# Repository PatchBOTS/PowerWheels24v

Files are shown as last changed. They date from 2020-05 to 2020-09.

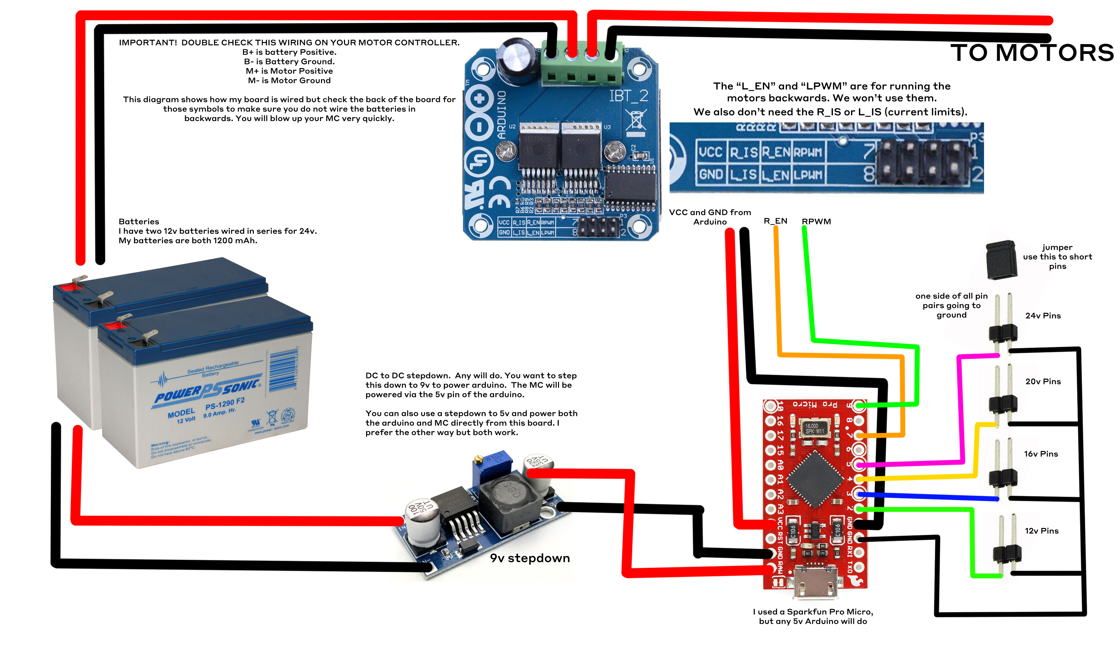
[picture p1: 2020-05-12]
Part1-HappyWife/Jeep Wiring Diagram.jpg

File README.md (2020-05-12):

24V (https://youtu.be/0GJBYLPPLp8)
# PowerWheels Jeep and Lightning McQueen Upgrades
Repository for all code and wiring for the project found in the video above. 
### Please Read Before Proceeding

I am not a professional anything.  This is a modfication I made to my childs vehicle based on my knowledge as a hobbyist and nothing more.  You are wiring batteries together to create more power than the intended use of the vehicle and then putting children in it. Use all the necessary pre-caution, caution and post caution that it deserves.  I take absolutely zero responsibility for anyone elses projects, this is just sharing what I did. I give no gaurantees on anything.  Take that for what it is worth.  

<a href="https://www.buymeacoffee.com/WjRBDa3dZ" target="_blank">Buy Me A Coffee</a>

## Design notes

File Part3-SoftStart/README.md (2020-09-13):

I've added two versions of the code.  The "DCDC" version is if you decide to use the DC to DC stepdown method instead of the digital switch method.

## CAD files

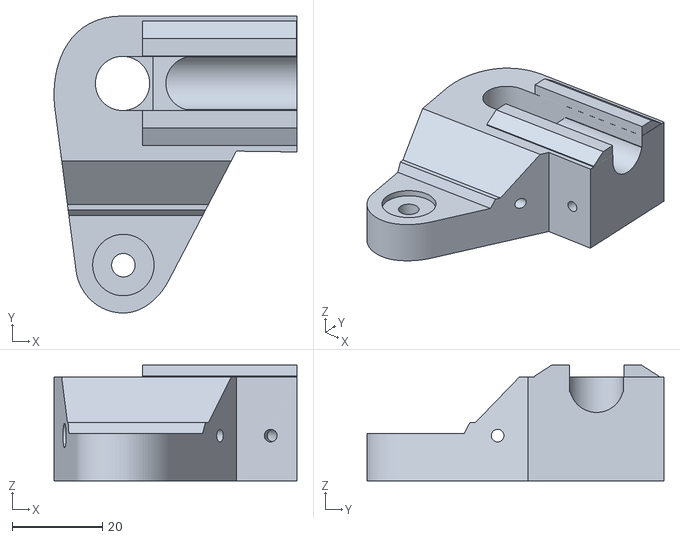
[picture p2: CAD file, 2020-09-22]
Part2-Steering/SteeringKnuckle1.stl
53.8 x 65.8 x 25.7

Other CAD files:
Part2-Steering/SteeringKnuckle2.stl

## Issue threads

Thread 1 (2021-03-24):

knuckle stl file

Mithantrum, 2021-03-24:
Evening! I downloaded the STL file but am not able to get it to open in Prusa Slicer, Blender, Fusion, or Cura. Woulld it be possible to get a re-upload or perhaps the gcode file?
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

DadMode, 2022-09-20:
First time user here. How do I download a file? All I can see is the really long code on the screen when trying to download the STL file. Thanks.

Mithantrum, 2022-09-21:
Just right click, save as. But per my issue above - it doesn't import into the slicer.

> First time user here. How do I download a file? All I can see is the really long code on the screen when trying to download the STL file. Thanks.

WIllyNilly33, 2022-11-18:
I had to drop it into voxelizer to convert to stl (https://drububu.com/miscellaneous/voxelizer/?out=stl). what's lost in translation is the size of the original object, do we know what the mm dimensions are to fit the powerwheel?

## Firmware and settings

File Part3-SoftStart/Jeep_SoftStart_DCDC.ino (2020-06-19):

// =======================================================================================
//                  PowerWheels Conversion-- Jeep Wrangler
// =======================================================================================
//                            Written By: PatchBOTS
// =======================================================================================
//                     microcontroller  ---  Sparkfun Pro Micro (5v)
// --------------------------------------------------------------------------------------
//
//                                 proMicro
//                                ------------
//                                |           |
//                     +--------------------------------+
//                     |                                |
//                     | [ ]TX                   RAW[ ] |  POWER IN
//                     | [ ]RX                   GND[ ] |  GND
//              GND    | [ ]GND                  RST[ ] |
//              GND    | [ ]GND                  VCC[ ] | MotorControllers
//      Speed 1 Jumper | [ ]2                     A3[ ] |
//      Speed 2 Jumper | [ ]3~                    A2[ ] |
//      Speed 3 Jumper | [ ]4                     A1[ ] |
//          Gas Switch | [ ]5~                    A0[ ] |
//           NeoPixel  | [ ]6~                    15[ ] |
//           MCEnable  | [ ]7                     14[ ] |
//                     | [ ]8                     16[ ] |
//               RPWM  | [ ]9~                   ~10[ ] | LPWM
//                     |                                |
//                     +--------------------------------+
//
//
// ---------------------------------------------------------------------------------------
//                                   NOTES
// ---------------------------------------------------------------------------------------

//A video build log for this project can be found here:  youtube.com/PatchBOTS

//I purposely didn't break this out into function based on the response I get from people on YouTube. 
//People looking to do this are usually non-coders who want to upgrade their kid's PowerWheels, so I didn't want to add any complexity where it wasn't necessary.
//I tried to be as verbose as possible with my comments, but feel free to email me with any additional questions. 

//There are a couple hardware changes from the previous version:
// I elimated on of the speed modes.  Previously I had 4 speeds (12v, 16v, 20v, and 24v).  My kids are well beyond 12v, so I just eliminated that and will have 3 speeds starting around 16v. 
// Since we have one less speed, we have an extra pin already wired in, so I'll use that for the gas pedal switch.  Pin 2 is the lowest speed (like before, even though it's faster now), Pin 3 for Speed 2, and Pin 4 for Speed 3, Pin 5 will be for the gas pedal switch. 

// ---------------------------------------------------------------------------------------
//                                   definitions
// ---------------------------------------------------------------------------------------

#define speedOne 2  //defines Pin 2 on the Arduino for Speed1
#define speedTwo 3  //defines Pin 3 on the Arduino for Speed2
#define speedThree 4 //defines Pin 4 on the Arduino for Speed3
#define Switch  5 //defines Pin 5 on the Arduino for the digital switch at the gas pedal
#define MCEnable 7  // This gets wired to R_EN on the BTS7960 motor controller. 
#define RPWM 9  // Wire this to RPWM on the BTS7960 motor controller. 
#define LPWM 10 // This isn't used in the code.  It would give us a reverse function via the motor controller, which isn't really useful in this setting. 


//Below are variables we will be using in the code.
int speed1 = 1; //all the speed control pins and the switch at the gas pedal work by grounding the pin (setting to 0). By setting it's inital value to 1 it keeps everything safely "off" at boot up.
int speed2 = 1;
int speed3 = 1;
int gasSwitch = 1;

int pwmWrite = 0; //default boot up speed is 0
int rampSpeed; //this will be the starting point of our "ramp ups" in Speed 2 and Speed 3



void setup() {  //this section just tells the arduino what pins will be doing what

  Serial.begin(38400);

  pinMode (speedOne, INPUT_PULLUP);
  pinMode (speedTwo, INPUT_PULLUP);
  pinMode (speedThree, INPUT_PULLUP);
  pinMode (Switch, INPUT_PULLUP);
  pinMode (MCEnable, OUTPUT);
  pinMode (RPWM, OUTPUT);
  pinMode (LPWM, OUTPUT);

  digitalWrite(MCEnable, HIGH); //enable the Microcontroller. This will need to reamin high in order to work.
}


// ---------------------------------------------------------------------------------------
//                                  MAIN PROGRAM LOOP
// ---------------------------------------------------------------------------------------

void loop() {  //THIS IS THE START OF OUR MAIN LOOP

  //**************************GET VALUES*********************************************

  speed1 = digitalRead(speedOne); //check to see if the jumper is on lowest setting
  speed2 = digitalRead(speedTwo); // check to see if the jumper is on the 2nd setting
  speed3 = digitalRead(speedThree); //check to see if the jumper is on the 3rd setting
  gasSwitch = digitalRead(Switch); //check to see if Gas Pedal is engaged

  //************************NO JUMPER PINS*****************
  if (speed1 == 1 && speed2 == 1 && speed3 == 1) { //this is just a safety measure.  If the jumper pin is not properly on any of the setting pins, the car does nothing.
    pwmWrite = 0; // you can change this value to have a default "no pin" speed.  The highest is 255 for 100% power.
    analogWrite(RPWM, pwmWrite);  //Send no pin value to Gas Pedal. We are not doing any soft start here, obviously.
  }

  //************************SPEED 1****************

  if (speed1 == 0) { // this is saying "if the jumper for speed1 is engaged, then change the PWM value to what is entered here.
    pwmWrite = 175; //this value determines the speed at the lowest setting. The number is out of 255 so in this case 175/255 is about 67%% power.  Change value as you see fit.
    analogWrite(RPWM, pwmWrite); //no soft start for 16v, just business as usual.
  }

  //************************SPEED 2 *****************

  if (speed2 == 0 ) { // this is saying "if the jumper for speed2 is engaged..."
    pwmWrite = 215; //this value determines the top PWM value at the 2nd setting. The number is out of 255 so in this case 215/255 is about 85% power. Change value as you see fit
    rampSpeed = 175; //Our goal is to ramp up to "pwmWrite."  I chose 175 as a starting point for that ramp based on the fact that I've run that value a lot without problems for the gears.
    while   (gasSwitch == 1 && speed2 ==0) { //this while loop stops everything while the gas pedal is open.
      analogWrite(RPWM, rampSpeed); //while the gas pedal is open, write our starting point to the motors.
      speed1 = digitalRead(speedOne); //check to see if the jumper is on lowest setting
      speed2 = digitalRead(speedTwo); // check to see if the jumper is on the 2nd setting
      speed3 = digitalRead(speedThree); //check to see if the jumper is on the 3rd setting
      gasSwitch = digitalRead(Switch); //check again to see to if gas pedal is pressed.
    }
    while (gasSwitch == 0 ) { //if Gas Pedal is pressed....
      if (rampSpeed < pwmWrite) { //and rampSpeed is below our top speed....
        rampSpeed++; //add 1 to ramp speed
        delay(45); //delay before running the previous two lines again.  In my bench tests, a 20ms delay equals a 1 second ramp up from 175 to 215.  40ms = 2 seconds, 60 = 3 seconds, 80 = 4 seconds and so on. This will vary, but a decent starting point.
      }
      analogWrite(RPWM, rampSpeed); //write the current value of rampSpeed (when the if statement catches up to the final "pwmWrite" speed, it will hang there until the foot is taken off the gas).
      gasSwitch = digitalRead(Switch); //check again to see to if gas pedal is pressed.
    }
  }

  //************************SPEED 3*****************

  if (speed3 == 0) { // this is saying "if the jumper for speed3 is engaged...."
    pwmWrite = 255; //this value determines the top PWM value at the this setting. The number is out of 255 so in this case 255/255 is about 100% power. Change value as you see fit
    rampSpeed = 175; //Our goal is to ramp up to "pwmWrite."  I chose 175 as a starting point for that ramp based on the fact that I've run that value a lot without problems for the gears.
    while   (gasSwitch == 1 && speed3 ==0) { //this while loop stops everything while the gas pedal is open.
      speed1 = digitalRead(speedOne); //check to see if the jumper is on lowest setting
      speed2 = digitalRead(speedTwo); // check to see if the jumper is on the 2nd setting
      speed3 = digitalRead(speedThree); //check to see if the jumper is on the 3rd setting
      analogWrite(RPWM, rampSpeed); //while the gas pedal is open, write our starting point to the motors.
      gasSwitch = digitalRead(Switch); //check again to see to if gas pedal is pressed.
    }
    while (gasSwitch == 0) { //if Gas Pedal is pressed....
      if (rampSpeed < pwmWrite) { //and rampSpeed is below our top speed....
        rampSpeed++; //add 1 to ramp speed
        delay(25); //delay before running the previous two lines again.  In my bench tests, a 10ms delay equals a 1 second ramp up from 175 to 255.  20ms = 2 seconds, 30 = 3 seconds, 40 = 4 seconds and so on. This will vary, but a decent starting point.
      }
      analogWrite(RPWM, rampSpeed); //write the current value of rampSpeed (when the if statement catches up to the final "pwmWrite" speed, it will hang there until the foot is taken off the gas).
      gasSwitch = digitalRead(Switch); //check again to see to if gas pedal is pressed.
    }

  }


}

//Use for debugging. 
/*
    Serial.print("PWM Write: ");
    Serial.print(pwmWrite);
    Serial.print(", ");
    Serial.print("RampSpeed: ");
    Serial.print(rampSpeed);
    Serial.print(", ");
    Serial.println("24V");
*/

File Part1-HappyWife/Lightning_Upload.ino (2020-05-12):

// =======================================================================================
//                  PowerWheels Conversion-- Lightning McQueen
// =======================================================================================
//                            Written By: PatchBOTS
// =======================================================================================
//                     microcontroller  ---  Sparkfun Pro Micro (5v)
// --------------------------------------------------------------------------------------
//
//                                 proMicro
//                                ------------
//                                |           |
//                     +--------------------------------+
//                     |                                |
//                     | [ ]TX                   RAW[ ] |  POWER IN
//                     | [ ]RX                   GND[ ] |  GND
//              GND    | [ ]GND                  RST[ ] |
//              GND    | [ ]GND                  VCC[ ] | MotorControllers
//                     | [ ]2                     A3[ ] |
//           MC Enable | [ ]3~                    A2[ ] |
//                     | [ ]4                     A1[ ] |
//                     | [ ]5~                    A0[ ] | Potentiometer
//                     | [ ]6~                    15[ ] |
//                     | [ ]7                     14[ ] |
//                     | [ ]8                     16[ ] |
//               RPWM  | [ ]9~                   ~10[ ] | 
//                     |                                |
//                     +--------------------------------+
//
// ---------------------------------------------------------------------------------------
//                                   definitions
// ---------------------------------------------------------------------------------------

#define MCEnable 3 //enable pin for Motor Controller, always high
#define RPWM 9 //sends signal to the Motor Controller
#define potentiometer A0 //reads knob 

//variables for code
int pot = 0;
int pwmWrite = 0;


void setup() { //Sets up our microcontroller 
 // Serial.begin(9600);  //enable for debugging
  pinMode (potentiometer, INPUT);
  pinMode (MCEnable, OUTPUT);
  pinMode (RPWM, OUTPUT);

  digitalWrite(MCEnable, HIGH);

}

void loop() { //THIS IS THE START OF OUR LOOP

  pot = analogRead(potentiometer); //read value of potentiometer 0-1024
  pwmWrite = constrain (map (pot, 0, 1024, 126, 257),128,255); //remap the 0-1024 to 126-257 and then only use values 128-255. THis gets rid of jitters at the extremes of the pot. 
  analogWrite (RPWM, pwmWrite); //write the value calculated above to the motorcontroller. 
//  Serial.println(pwmWrite); //enable for debugging

} //REPEAT LOOP
